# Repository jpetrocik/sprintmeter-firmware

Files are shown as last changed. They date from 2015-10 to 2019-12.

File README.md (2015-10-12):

# sprintmeter-firmware
A BMX sprint timer for logging sprint times both on and off the track.

Sprint data is sent via bluetooth to Android devices.  Leveleraging the display and storage capacity of Android 
smartphone and tablets to display and log spring data.  Unlike normal bike computers that display only current speed,
max speed, and distance sprintmeter logs data at 3-4 times a revolution.  SprintMeter shows speed, distance, and time
at 16" intervals.

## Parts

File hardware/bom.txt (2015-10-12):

Part    Value            Device               Package                Description                                                                                                                 
BATTERY BATHOLDER-N-2470 BATHOLDER-N-2470     BATHOLDER-N-2470       Digi-Key Part Number                                                                                              KEY1123-ND
C1      10uF             CAP_POL1206          EIA3216                Capacitor Polarized                                                                                                         
C2      68uF             CAP_POL3528          EIA3528                Capacitor Polarized                                                                                                         
D3      MBRA140          DIODESMA             SMA-DIODE              Diode                                                                                                                       
L1      47uH             INDUCTORCR54         CR54                   Inductors                                                                                                                   
Q1                       TRANSISTOR_NPNSOT23  SOT23                  Generic NPN BJT. MMBT2222 is the common NPN we use. 
R4      1K               RESISTOR0805-RES     0805                   Resistor                                                                                                                    
REED    M02              M02                  1X02-SMD_EDGE          Standard 2-pin 0.1" header. Use with                                                                                        
U$1     24AAXXX          24AAXXX              SOIC-8-EIAJ                                                                                                                                        
U$2     AVR_SPI_PROG3    AVR_SPI_PROG3        1X06-SMD_EDGE          SMD edge programer                                                                                                          
U1      NCP1402          V_REG_NCP1400SOT23-5 SOT23-5                Switching step-up voltage regulator                                                                                         
U2      ATMEGA168        ATMEGA168            TQFP32-08              Atmel 32-pin 8-bit micro, 16k flash.

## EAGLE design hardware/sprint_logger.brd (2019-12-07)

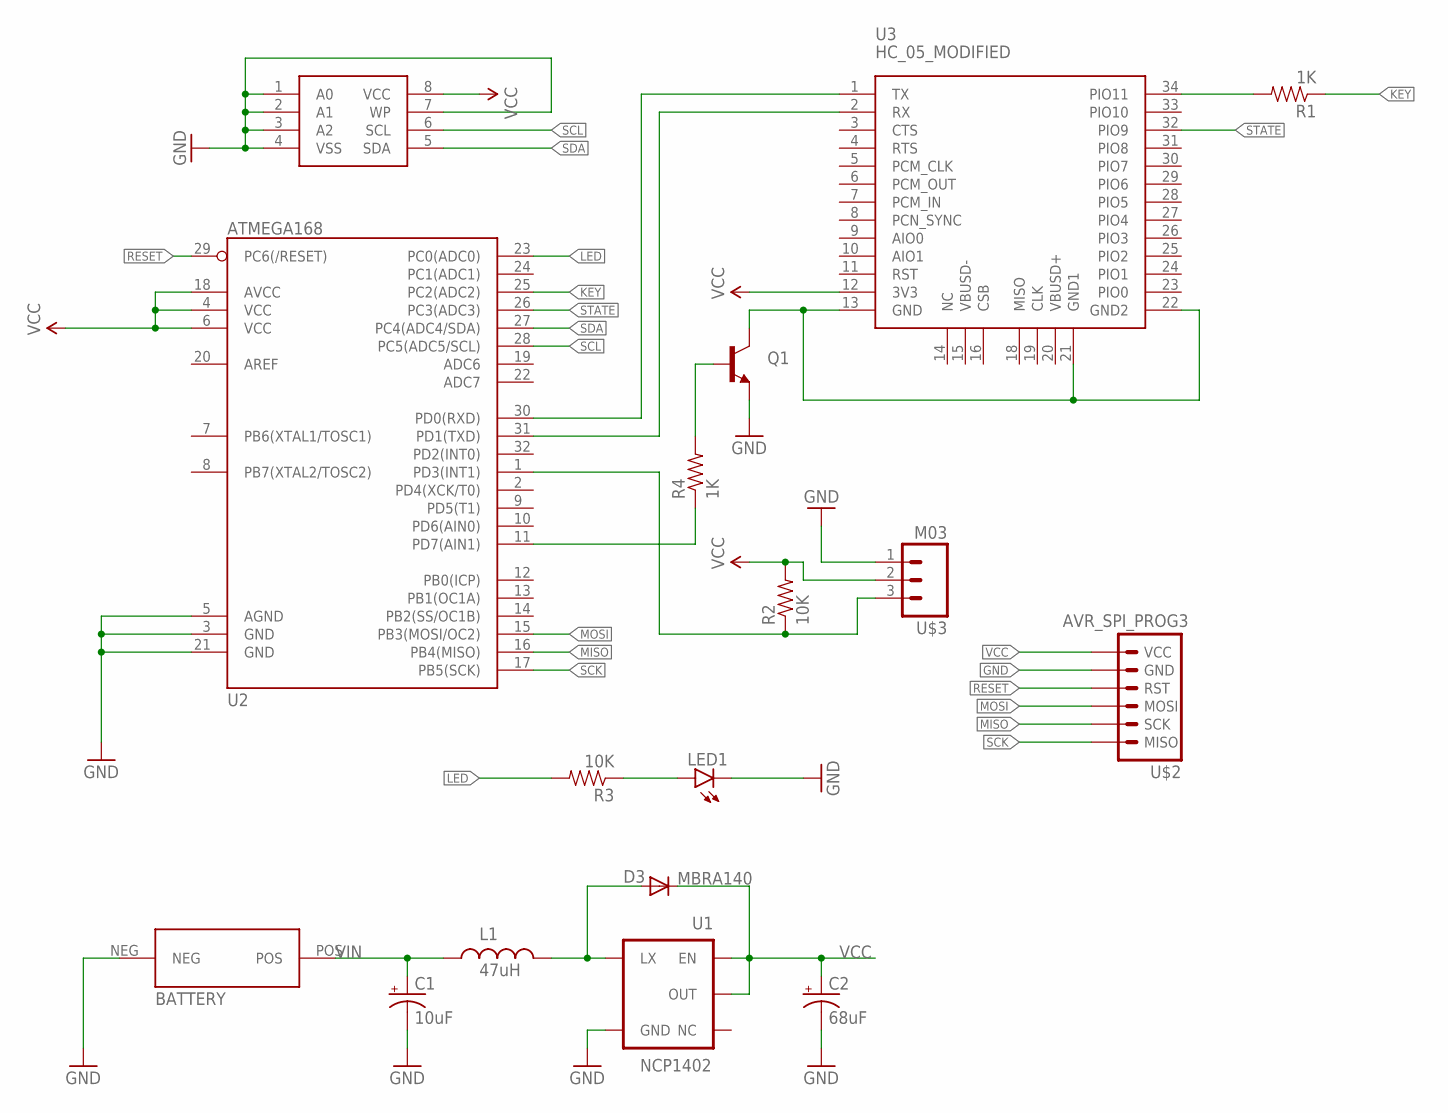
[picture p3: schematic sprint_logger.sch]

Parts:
BATTERY: BATHOLDER-N-2470
C1: 10uF; EIA3216
C2: 68uF; EIA3528
D3: MBRA140; SMA-DIODE
L1: 47uH; CR54
LED1: LED1206; LED-1206
Q1: TRANSISTOR_NPNSOT23; SOT23
R1, R4: 1K; 0805
R2, R3: 10K; 0805
U1: NCP1402; SOT23-5
U2: ATMEGA168; TQFP32-08
U3: HC_05_MODIFIED; BLUETOOTH_SMD_MODIFIED
U$1: 24AAXXX; SOIC-8-EIAJ
U$2: AVR_SPI_PROG3; 1X06-SMD_EDGE
U$3: M03; 1X06-SMD_EDGE

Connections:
GND: BATTERY.NEG, C1.C (-), C2.C (-), LED1.C, Q1.2 (E), U1.4 (GND), U2.3 (GND), U2.5 (AGND), U2.21 (GND), U$1.1 (A0), U$1.2 (A1), U$1.3 (A2), U$1.4 (VSS), U$1.7 (WP), U$2.2 (GND), U$3.1
KEY: R1.1, U2.25 (PC2(ADC2))
LED: R3.2, U2.23 (PC0(ADC0))
MISO: U2.16 (PB4(MISO)), U$2.5 (SCK)
MOSI: U2.15 (PB3(MOSI/OC2)), U$2.4 (MOSI)
unnamed: R2.1, U2.1 (PD3(INT1)), U$3.3
unnamed: D3.A, L1.P$2 (2), U1.5 (LX)
unnamed: U2.30 (PD0(RXD)), U3.1 (TX)
unnamed: U2.31 (PD1(TXD)), U3.2 (RX)
unnamed: Q1.3 (C), U3.13 (GND), U3.21 (GND1), U3.22 (GND2)
unnamed: LED1.A, R3.1
unnamed: Q1.1 (B), R4.2
unnamed: R4.1, U2.11 (PD7(AIN1))
unnamed: R1.2, U3.34 (PIO11)
RESET: U2.29 (PC6(/RESET)), U$2.3 (RST)
SCK: U2.17 (PB5(SCK)), U$2.6 (MISO)
SCL: U2.28 (PC5(ADC5/SCL)), U$1.6 (SCL)
SDA: U2.27 (PC4(ADC4/SDA)), U$1.5 (SDA)
STATE: U2.26 (PC3(ADC3)), U3.32 (PIO9)
VCC: C2.A (+), D3.C, R2.2, U1.1 (EN), U1.2 (OUT), U2.4 (VCC), U2.6 (VCC), U2.18 (AVCC), U3.12 (3V3), U$1.8 (VCC), U$2.1 (VCC), U$3.2
VIN: BATTERY.POS, C1.A (+), L1.P$1 (1)

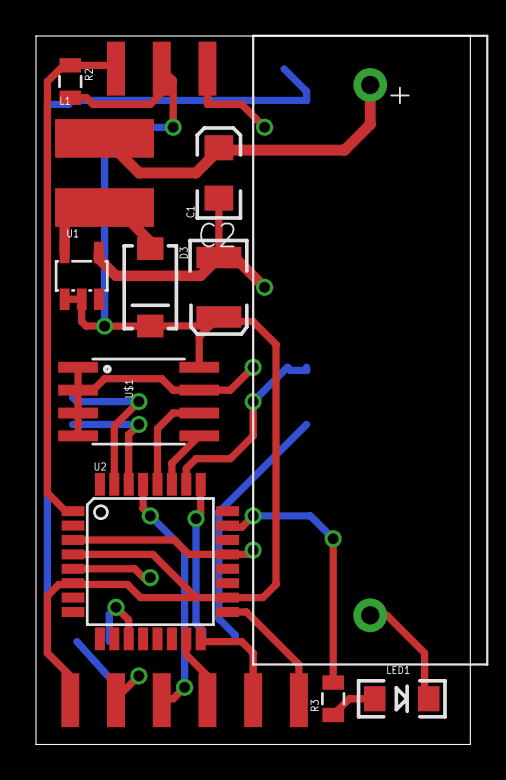
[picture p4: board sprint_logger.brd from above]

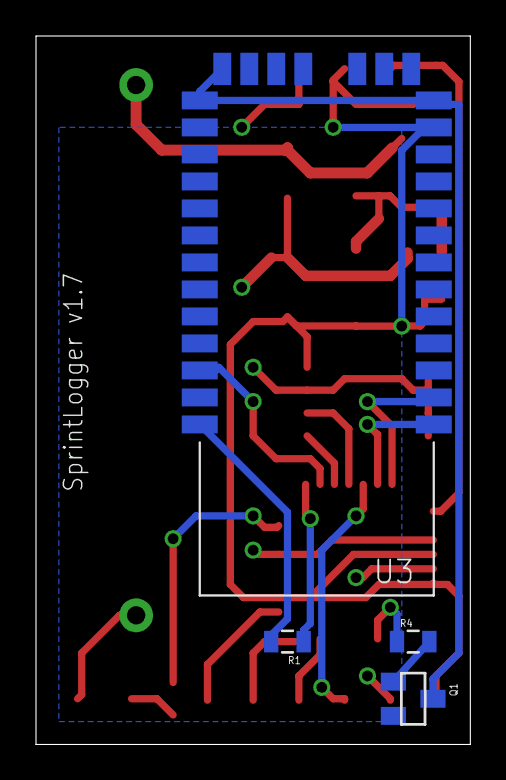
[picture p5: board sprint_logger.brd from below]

Board: 2 copper layers, 24.1 x 39.4 mm, 17 parts (4 on the bottom side), 21 nets.

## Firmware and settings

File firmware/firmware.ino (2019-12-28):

//#include <Wire.h>
#include <avr/sleep.h>
#include <Ticker.h>
//#include "sleep.h"

/**
   Board Notes

   v1.3
   Removed EEPROM

   v1.2
   Enable Internal PullUp
   Check Interrupts: Reed Falling, Wake Low
*/

#define SLEEP_ENABLED

#define BOUNCE_DELAY 5

#define STATE A3
#define KEY A2
#define WHEEL_SENSOR 3
#define BT_ENABLE 7
#define RED_LED  A0

#define SLEEP 180000000L
//#define SLEEP 15000000L
#define DATA_BUFFER 1500 //about 1000' of buffered data

unsigned long previousTriggerTime = 0;
unsigned int seqChecksum = 0;
volatile unsigned long triggeredTime = 0;
volatile int triggered = false;
volatile int error = false;

void tick();

Ticker ledTicker(tick, 250);

void setup() {
  Serial.begin(115200);
  pinMode(RED_LED, OUTPUT);
  pinMode(KEY, OUTPUT);
  pinMode(BT_ENABLE, OUTPUT);
  pinMode(STATE, INPUT_PULLUP);
  pinMode(WHEEL_SENSOR, INPUT);

  //Turn on i2c and set to 400Hz
  //Wire.begin();
  //TWBR = 12;

  //http://www.gammon.com.au/power
  //disable ADC for power savings
  ADCSRA = 0;

  enableBluetooth();

  attachInterrupt(1, sensorRead_isr, FALLING);

  ledTicker.start();
}

void enableBluetooth() {
  digitalWrite(BT_ENABLE, LOW);
  digitalWrite(KEY, LOW);
  delay(1000);
  digitalWrite(BT_ENABLE, HIGH);
}

void tick() {
  int state = digitalRead(RED_LED);
  digitalWrite(RED_LED, !state);
}

void loop() {
  ledTicker.update();

  int btConnected = digitalRead(STATE);
  if (!btConnected && ledTicker.state() == STOPPED) {
    ledTicker.start();
  } else if (btConnected) {
    ledTicker.stop();
    digitalWrite(RED_LED, HIGH);
  }

  //check for new data
  if (triggered) {
    //calculate current split time
    unsigned long split = triggeredTime - previousTriggerTime;
    seqChecksum++;

    //save previous trigger time to calcuate split next trigger
    previousTriggerTime = triggeredTime;

    //TODO Improve error handling
    if (error) {
      seqChecksum++;
      error = false;
    }
    
    if (btConnected) {

      //sends split and seqCheck
      //to ensure message wasn't lost
      Serial.print("BMX");
      Serial.write(split >> 24);
      Serial.write(split >> 16);
      Serial.write(split >> 8);
      Serial.write(split);
      Serial.write(seqChecksum >> 8);
      Serial.write(seqChecksum);

    }
    triggered = false;
  }

#ifdef SLEEP_ENABLED
  //goto sleep after long delay
  long lastRead = micros() - triggeredTime;
  if ( lastRead > SLEEP) {
    ledTicker.stop();

    digitalWrite(BT_ENABLE, LOW);
    digitalWrite(RED_LED, LOW);

    //remove current interrupt, sensorRead_isr()
    detachInterrupt(1);

    //disable ADC
    ADCSRA = 0;

    set_sleep_mode(SLEEP_MODE_PWR_DOWN);
    noInterrupts();
    sleep_enable();

    //setup new interrupt, wake_isr()
    attachInterrupt(1, wake_isr, HIGH);

    // turn off brown-out enable in software
    MCUCR = bit (BODS) | bit (BODSE);
    MCUCR = bit (BODS); 
  
    interrupts();
    sleep_cpu();
  }
#endif

}

/*
   Triggered by magnet to record time
*/
void sensorRead_isr() {
  if (triggered) {
    error = true;
    return;
  }

  triggeredTime = micros();
  triggered = true;
}

/*
   Triggered by magnet to wake up when in sleep mode
*/
#ifdef SLEEP_ENABLED
void wake_isr()
{
  sleep_disable();
  detachInterrupt(1);

  digitalWrite(BT_ENABLE, HIGH);
  digitalWrite(RED_LED, HIGH);

  attachInterrupt(1, sensorRead_isr, FALLING);

  triggeredTime = micros();
}
#endif

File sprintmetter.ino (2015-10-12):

#include <avr/sleep.h>
#include "sleep.h"

/**
 * Board Notes
 *
 * v1.3 
 * Removed EEPROM
 * 
 * v1.2 
 * Enable Internal PullUp
 * Check Interrupts: Reed Falling, Wake Low
 */


#define BOUNCE_DELAY 20

#define REED_SENSOR 3
#define BT_ENABLE 7
#define RED_LED  5
#define SLEEP 1200000
#define DATA_BUFFER 1500 //about 1000' of buffered data

//current read set by interrupt
volatile long triggeredTime;
volatile int triggered = false;

long data[DATA_BUFFER];  
int dataStart = 0;   //set to 1 so first interrupt wont result in out of bounds error
int dataEnd = 0;  //set to 1 so first interrupt wont result in out of bounds error
int dataOverflow=0; //set when previous read hasn't been processed



void setup(){
  Serial.begin(9600);

  //Turn on i2c and set to 400Hz
  Wire.begin();
  TWBR = 12;

  // disable ADC for power savings
  ADCSRA = 0;

  pinMode(REED_SENSOR, INPUT_PULLUP);
  pinMode(BT_ENABLE, OUTPUT);
  pinMode(RED_LED, OUTPUT);

  digitalWrite(BT_ENABLE, HIGH);
  digitalWrite(RED_LED, HIGH);

  attachInterrupt(1, sensorRead_isr, FALLING);
  
  for (int i = 0; i < 32; i++){
    data[i]=0;
  }
}

void loop(){

  //check for new data
  if (triggered){
    int previousSpltcksum = data[dataEnd%DATA_BUFFER];
    int split = 0;

    split = triggeredTime-checksum;
    
    //save split time
    dataEnd++;
    data[dataEnd%DATA_BUFFER] = split;
    
    
    //sends split and checksum
    //to ensure message wasn't lost
    //previous_checksum + split = checksum
    Serial.print("BMX");
    Serial.write(split>>8);
    Serial.write(split);
    Serial.write(checksum>>24);
    Serial.write(checksum>>16);
    Serial.write(checksum>>8);
    Serial.write(checksum);

    triggered=false;
  }
  
  //goto sleep after long delay
  if (millis() - triggeredTime > SLEEP){
    digitalWrite(BT_ENABLE, LOW);
    digitalWrite(RED_LED, LOW);

    detachInterrupt(1);

    sleep_enable();
    attachInterrupt(1, wake_isr, HIGH);
    set_sleep_mode(SLEEP_MODE_PWR_DOWN);
    cli();
    sei();
    sleep_cpu();
    sleep_disable();

    digitalWrite(BT_ENABLE, HIGH);
    digitalWrite(RED_LED, HIGH);
    attachInterrupt(1, sensorRead_isr, FALLING);

  }
}

/* 
 * Triggered by magnet to record time
 */
void sensorRead_isr(){
  long now = millis();
  if( now - triggeredTime > BOUNCE_DELAY ){
    triggeredTime=millis();
    triggered=true;
  }
}

/*
 * Triggered by magnet when in sleep mode
 */
void wake_isr()
{
  sleep_disable();
  detachInterrupt(0);
  triggeredTime=millis();
}

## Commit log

2015-10-12 Adding schematics
    [sprint_logger.brd, sprint_logger.sch]
2019-12-07 Intial v1.6 commit
    [sprint_logger.brd, sprint_logger.sch]
2019-12-18 sleep revamped, sprint activity cleaned up, auto detected track sprints

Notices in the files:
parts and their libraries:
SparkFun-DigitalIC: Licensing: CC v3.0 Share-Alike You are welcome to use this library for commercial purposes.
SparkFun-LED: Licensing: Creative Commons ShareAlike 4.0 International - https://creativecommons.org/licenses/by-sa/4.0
